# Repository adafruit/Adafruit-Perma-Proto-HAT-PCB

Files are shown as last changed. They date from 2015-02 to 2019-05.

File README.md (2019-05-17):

# Adafruit Perma-Proto HAT for Raspberry Pi Computers

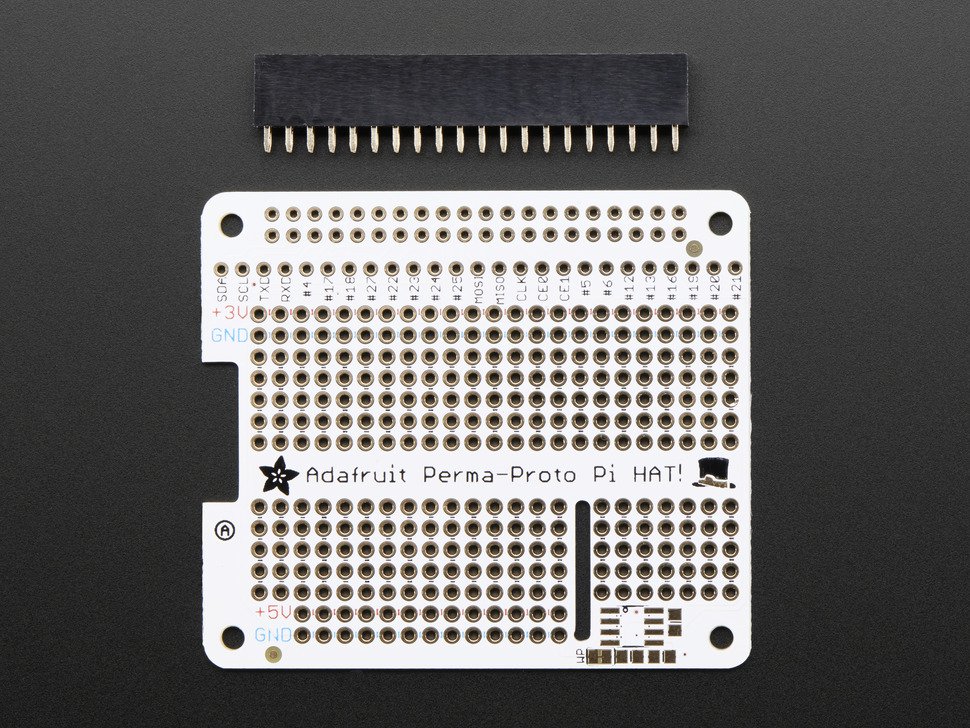
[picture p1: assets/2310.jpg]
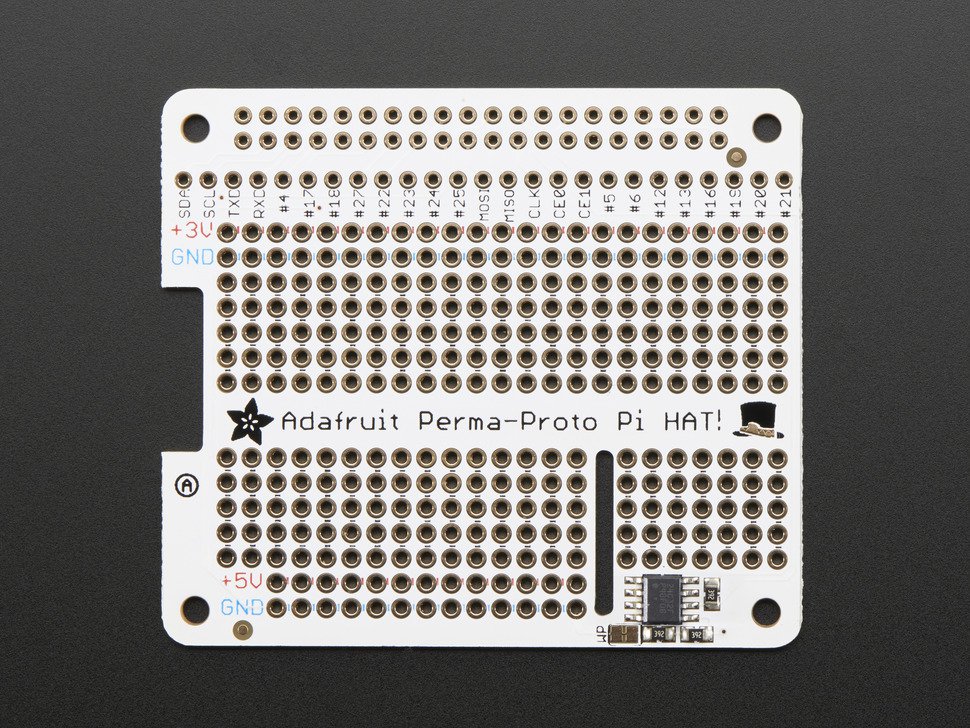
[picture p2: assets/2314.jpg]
&nbsp; <br />
Click to purchase from the Adafruit Shop:
- [With EEPROM](https://www.adafruit.com/product/2314)
- [Without EEPROM](https://www.adafruit.com/product/2310)

PCB files for the Adafruit Perma-Proto HAT for Raspberry Pi Computers (all with the 40 pin header)

Design your own Pi HAT, attach custom circuitry and otherwise dress your Pi Zero, A+, B+, Pi 2 or Pi 3 (any Pi with a 2x20 connector) with this jaunty prototyping HAT kit.

To kick off the Adafruit HAT party, we have this Perma-Proto inspired plug in daughter board. It has a grid of 0.1" prototyping soldering holes for attaching chips, resistors, LED, potentiometers and more. The holes are connected underneath with traces to mimic the solderless breadboards with which you're familiar. There's also long power strips for +3V, +5V and Ground connections to the Pi. Near the top we break out nearly every pin you could want to connect to the Pi (#26 didn't quite make the cut).

This is just the basic version of our Perma-Proto HAT.  It comes with a printed circuit board and a single 2x20 GPIO Header for Raspberry Pi to put your Perma-Proto on top of your Raspberry Pi (like a nice little hat...) This version does not come with an EEPROM so you can 'stack' it with other HATs without worrying about an EEPROM address collision.

Format is EagleCAD schematic and board layout

For more details, check out the product pages at

-----> https://www.adafruit.com/products/2310

-----> https://www.adafruit.com/products/2314

### License

Adafruit invests time and resources providing this open source design, please support Adafruit and open-source hardware by [purchasing products from Adafruit](https://www.adafruit.com)!

All text above must be included in any redistribution

Designed by Limor Fried/Ladyada for Adafruit Industries.
Creative Commons Attribution/Share-Alike, all text above must be included in any redistribution 
See license.txt for additional information.

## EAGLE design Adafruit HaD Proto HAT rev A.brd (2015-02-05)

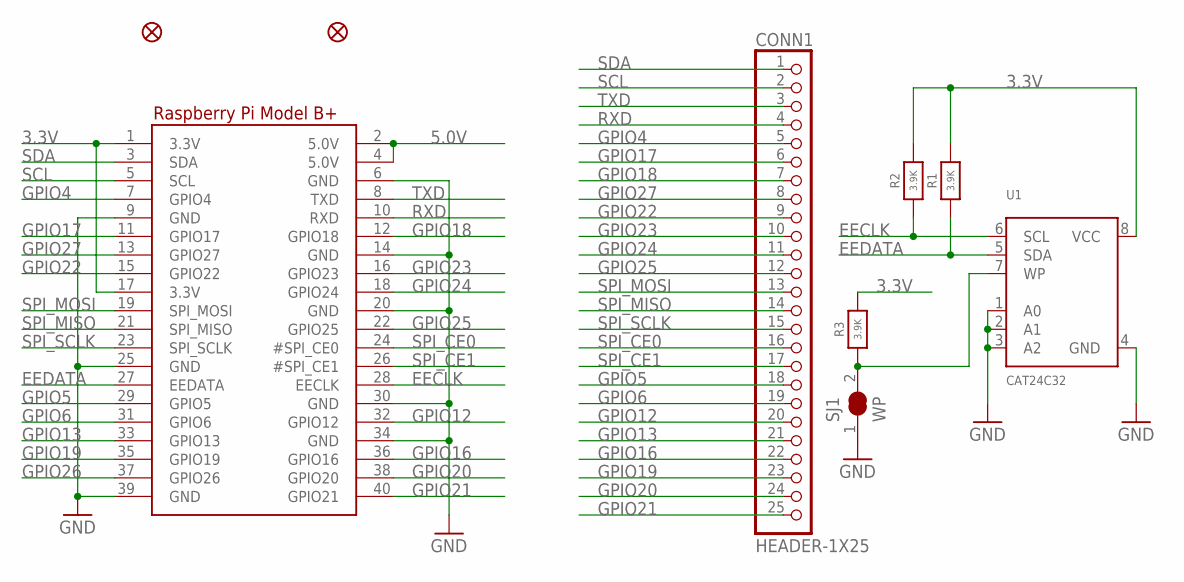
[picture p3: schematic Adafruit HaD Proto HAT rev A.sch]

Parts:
CONN1: HEADER-1X25; 1X25_ROUND_70MIL
FID2, FID3: FIDUCIAL""; FIDUCIAL_1MM
R1, R2, R3: 3.9K; 0805-NO
RPI1: RASPBERRYPI_BPLUS_HATNOSLOTS; PI_HAT_NOSLOTS
SJ1: WP; SOLDERJUMPER_CLOSEDWIRE
U1: CAT24C32; SOIC8_150MIL

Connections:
3.3V: R1.2, R2.2, R3.2, RPI1.1 (3.3V), RPI1.17 (3.3V), U1.8 (VCC)
5.0V: RPI1.2 (5.0V), RPI1.4 (5.0V)
EECLK: R2.1, RPI1.28 (EECLK), U1.6 (SCL)
EEDATA: R1.1, RPI1.27 (EEDATA), U1.5 (SDA)
GND: RPI1.6 (GND), RPI1.9 (GND), RPI1.14 (GND), RPI1.20 (GND), RPI1.25 (GND), RPI1.30 (GND), RPI1.34 (GND), RPI1.39 (GND), SJ1.1, U1.1 (A0), U1.2 (A1), U1.3 (A2), U1.4 (GND)
GPIO4: CONN1.5, RPI1.7 (GPIO4)
GPIO5: CONN1.18, RPI1.29 (GPIO5)
GPIO6: CONN1.19, RPI1.31 (GPIO6)
GPIO12: CONN1.20, RPI1.32 (GPIO12)
GPIO13: CONN1.21, RPI1.33 (GPIO13)
GPIO16: CONN1.22, RPI1.36 (GPIO16)
GPIO17: CONN1.6, RPI1.11 (GPIO17)
GPIO18: CONN1.7, RPI1.12 (GPIO18)
GPIO19: CONN1.23, RPI1.35 (GPIO19)
GPIO20: CONN1.24, RPI1.38 (GPIO20)
GPIO21: CONN1.25, RPI1.40 (GPIO21)
GPIO22: CONN1.9, RPI1.15 (GPIO22)
GPIO23: CONN1.10, RPI1.16 (GPIO23)
GPIO24: CONN1.11, RPI1.18 (GPIO24)
GPIO25: CONN1.12, RPI1.22 (GPIO25)
GPIO26: RPI1.37 (GPIO26)
GPIO27: CONN1.8, RPI1.13 (GPIO27)
unnamed: R3.1, SJ1.2, U1.7 (WP)
RXD: CONN1.4, RPI1.10 (RXD)
SCL: CONN1.2, RPI1.5 (SCL)
SDA: CONN1.1, RPI1.3 (SDA)
SPI_CE0: CONN1.16, RPI1.24 (#SPI_CE0)
SPI_CE1: CONN1.17, RPI1.26 (#SPI_CE1)
SPI_MISO: CONN1.14, RPI1.21 (SPI_MISO)
SPI_MOSI: CONN1.13, RPI1.19 (SPI_MOSI)
SPI_SCLK: CONN1.15, RPI1.23 (SPI_SCLK)
TXD: CONN1.3, RPI1.8 (TXD)

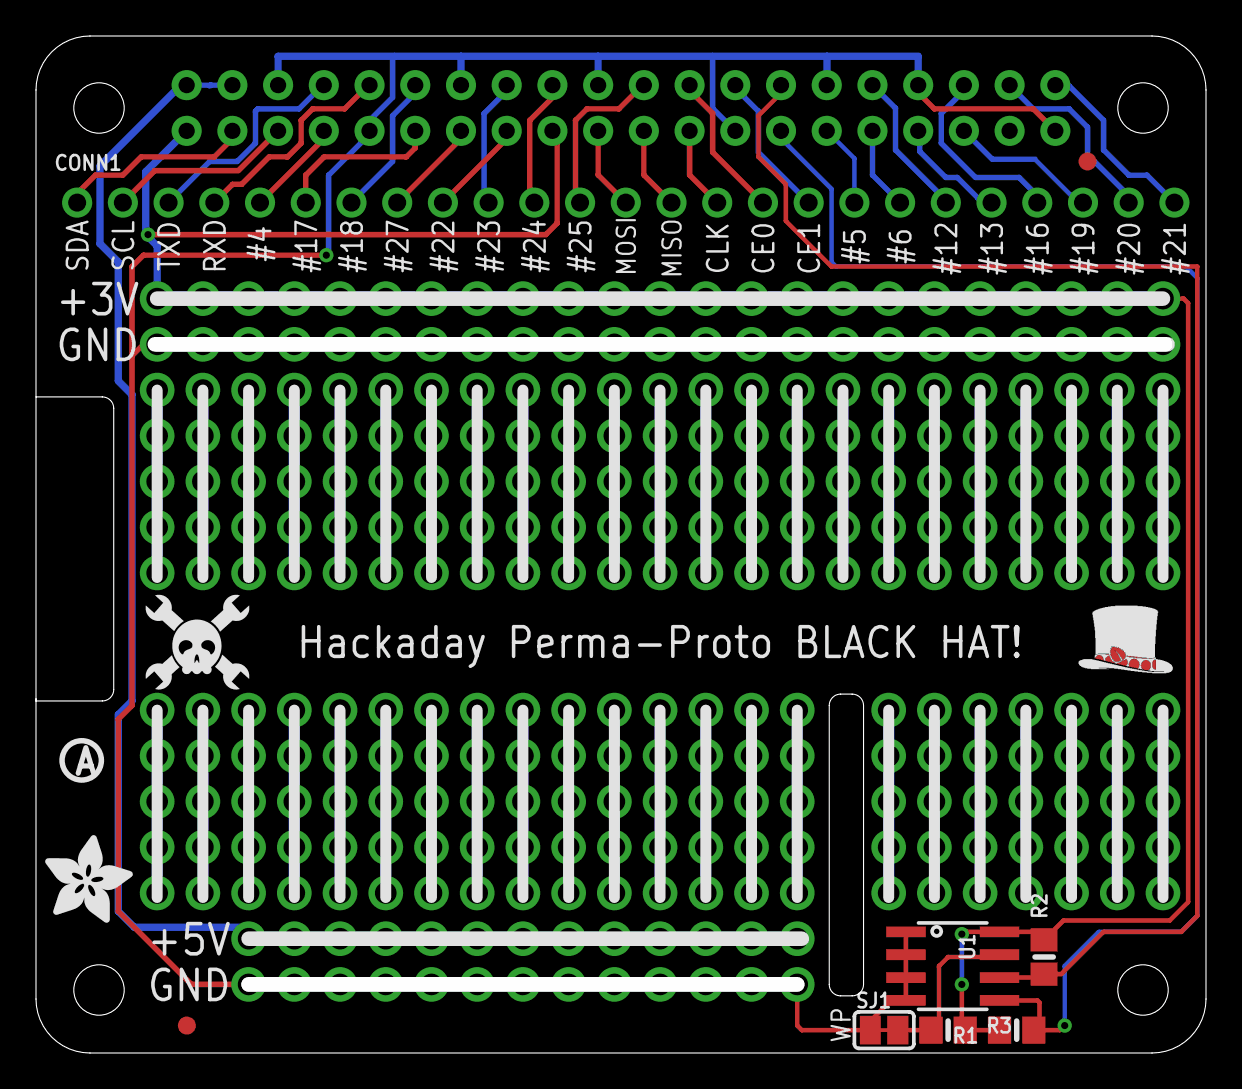
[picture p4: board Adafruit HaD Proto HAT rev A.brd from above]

Board: 2 copper layers, 65.0 x 56.5 mm, 13 parts (0 on the bottom side), 31 nets.

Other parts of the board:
U$1: ADAFRUIT_5MM
U$2: PIHATLOGO
U$3: PCBFEAT-REV-056
U$5: HAD_LOGO_200MIL

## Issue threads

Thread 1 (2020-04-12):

fix board dimensions

waspinator, 2020-04-12:
The backwards C-shaped cutout on the left isn't being cut out properly since the dimensions turn it into a D. There are also two seemingly random lines.

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

https://upverter.com/eda/#designId=4e788e21ea5ffb0e,tool=pcb

liqdfire, 2020-06-25:
I found this post on their forums that say the microbuilder library is internal only. However, you can export it from an existing design into a new library, and make modifications there.

https://forums.adafruit.com/viewtopic.php?t=129613

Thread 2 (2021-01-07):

No breakout for GPIO26

colemarkham, 2021-01-07:
It's the only pin not broken out. I understand there wasn't room in the main row for another pin, but it would have been nice to have it somewhere on the board. Otherwise I have to solder onto the header pin. Not a huge deal, but it seems odd.

ladyada, 2021-01-07:
a sacrifice was made! :)

Closed 2021-01-07.

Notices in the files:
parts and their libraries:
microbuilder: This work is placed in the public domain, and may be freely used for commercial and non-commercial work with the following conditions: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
